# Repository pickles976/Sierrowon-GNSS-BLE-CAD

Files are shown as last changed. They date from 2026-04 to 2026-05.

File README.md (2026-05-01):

# README

## BOM

RS232 converter 
https://www.digikey.com/en/products/detail/texas-instruments/TRSF3232EIPWR/1909461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

ESP32-S3-Mini
https://www.digikey.com/en/products/detail/espressif-systems/ESP32-S3-MINI-1-N4R2/22597234
https://learn.adafruit.com/assets/110822

Power Supply
https://www.digikey.com/en/products/detail/recom-power/RPX-4-0-R/14312389

TODO: which pins from the GPS module do what?

## 12-Pin Connector Pin Assignment

| Header Pin | Signal | Module Pin | GPIO | Notes |
| --- |---|---|---|---|
| 01 | GND | — | — | Power rail |
| 02 | GND | — | — | Power rail |
| 03 | CS | 34 | IO38 | SPI — cleanest GPIO in range |
| 04 | IO_4 | 38 | IO42 | JTAG-capable, free as GPIO |
| 05 | MISO | 33 | IO37 | SPI — native FSPIQ |
| 06 | IO_3 | 37 | IO41 | JTAG-capable, free as GPIO |
| 07 | MOSI | 31 | IO35 | SPI — native FSPID |
| 08 | IO_2 | 36 | IO40 | JTAG-capable, free as GPIO |
| 09 | SCK | 32 | IO36 | SPI — native FSPICLK |
| 10 | IO_1 | 35 | IO39 | JTAG-capable, free as GPIO |
| 11 | 12V (GNSS Vin) | — | — | Power rail |
| 12 | 3.3V | — | — | Power rail |

> **Note:** Avoid using module pin 26 (IO26) as GPIO — on the N4R2, IO26 is internally tied to PSRAM in QIO mode and will cause corruption if driven externally. Avoid pins 39–40 (GPIO43/44, UART0 TX/RX) and pin 41 (IO45, VDD_SPI strapping pin). Pins 31–33 (IO35–IO37) have eFuse-determined defaults but are free in QIO flash mode. Pins 35–38 (IO39–IO42) are JTAG by default but freely reassignable; USB-JTAG still works regardless.

+12V trace is 2A, needs to be 1.5mm

Cheers
https://documentation.espressif.com/esp32-s3_datasheet_en.pdf#cd-pins-peri-assignment Page 27
https://documentation.espressif.com/esp32-s3-mini-1_mini-1u_datasheet_en.pdf Page 20

Output from GPS module: 9-36V (nominally 12V)
Output from Buck Converter: 3.3V

### Things to Study:
- schematic blocks
- pcb manufacturing
- set up redmine for documentation

```
for all resistors and capacitors you can use 0603 or 0805, diodes can be SMA, LEDs can also be 0603 or 0805, and kicad should have some footprints for some common pushbutton switches.

For the 52uF it would have to be 1206 most likely.. instead of putting +V_OUT its better just to put the actual voltage, like the +3V3 symbol, and then you dont need the power flags as well (unless you want to pass ERC everywhere)
usually you determine footprints for resistors and capacitors based on what is generally available on digi-key and mouser, but mostly they should all be 0603 and 0805
you can also just place a couple 22uF in parallel to get the 52uF since thats a more common size and we can reduce the BOM. Each additional part equates to an additional feeder on a pick and place and costs more to setup
the ESP should have a 22uF near the VIN pin, and you can use that some one 3x on the output of the buck converter

Ok I dont have a lot of time to go through this in detail, but some things I noticed in layout

Try to create more space between the USB-C connector and the ESP's antenna, preferrably swaping places with the USB-C and the 12 pin
Remove the little sliver of ground pour above the antenna, I would just move the ESP32 up more to eliminate that and get it right on the edge of the board.
I would add a lot of stitching vias around the GND pins of the ESP32 to connect the two ground pours on top and bottom.

I personally would recommend a 4-layer stackup so we can have a dedicated 3.3V ground pour and increase overall board capacitance, the ESP's wifi TX events can cause a good inrush current and from an EMI perspective we are creating a large current loops with 3.3V routed the way it is

```

### Workflow Stuff

The DXF files are generated from the full .step file of the BLE adapter. Then we import the outer ring and screw holes as the edge cuts of the board. A DXF containing all lines in the sketch is imported to the "user drawings" layer so we can see where our via holes need to go for the pins.

Layers
1. GND
2. GND
3. +3V3
4. GND

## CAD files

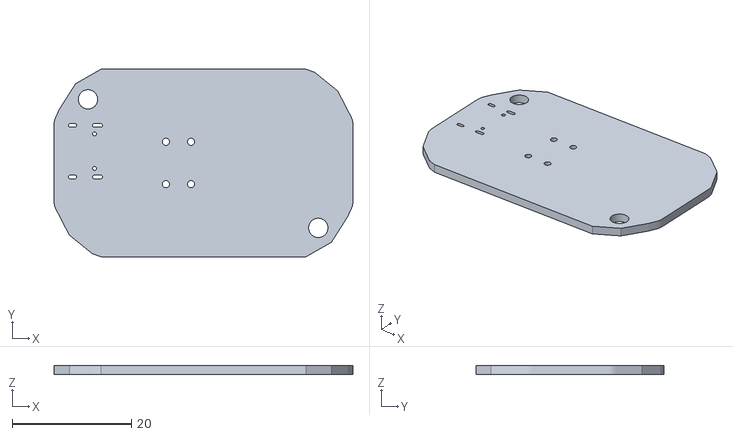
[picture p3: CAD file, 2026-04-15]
BLE-Module/.stl
50.0 x 31.4 x 1.51

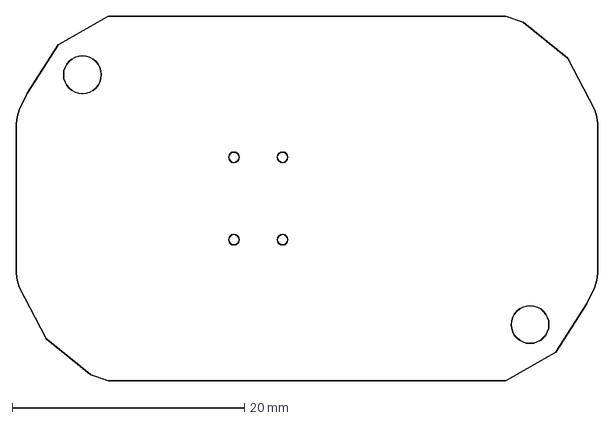
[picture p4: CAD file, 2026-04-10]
Reference/PCB for BLE interface.dxf
50.0 x 31.4 mm

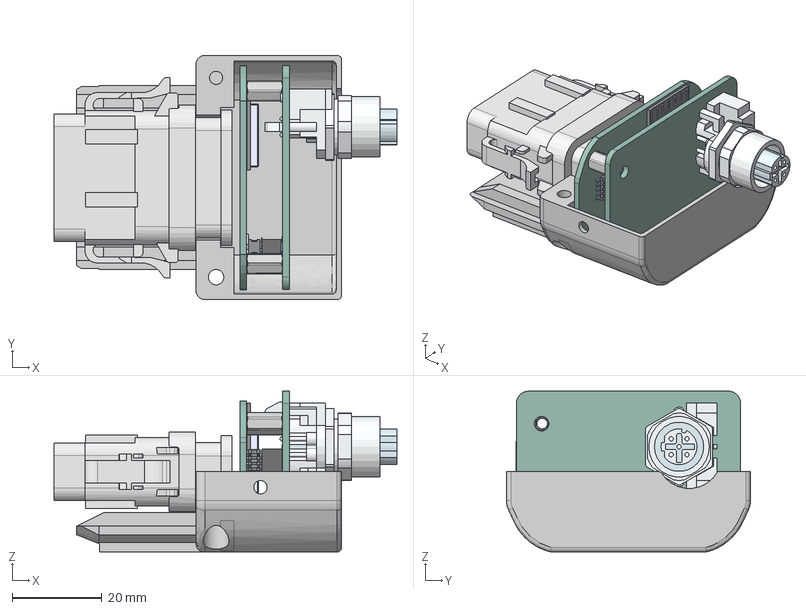
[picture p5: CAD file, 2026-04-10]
Reference/BLE V4 - Proto.step
76.5 x 54.5 x 35.9 mm
ESP32-S3-MINI-1-N4R2
ATM06-12SA-SR1GYPART1
ATM06-12SA-SR1GYSR
enclosure
PCB1
PCB2
FLE-105-01-DV_socket
C-96-01-05-DV
K-DOT-0.1675-0.281-0.005_polyamide_pick
FTSH-105-01-L-DV
94868A164_Female Threaded Hex Standoff x 2

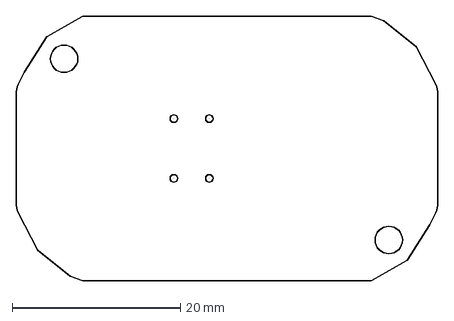
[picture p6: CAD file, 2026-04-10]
Reference/BOARD_TRACE.dxf
50.0 x 31.4 mm

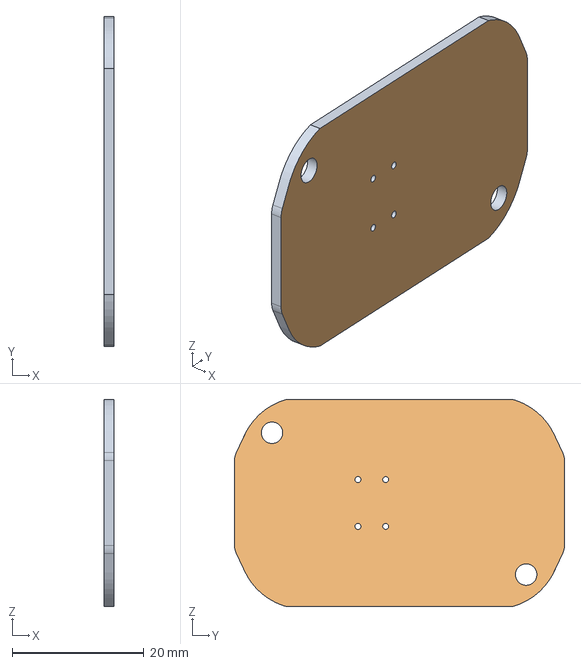
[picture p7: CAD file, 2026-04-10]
Reference/board_layout.FCStd
1.50 x 50.0 x 31.4 mm
PCB1
Binder

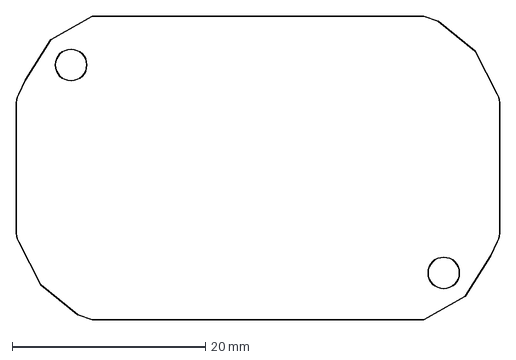
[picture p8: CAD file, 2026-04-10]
Reference/BOARD_OUTLINE.dxf
50.0 x 31.4 mm

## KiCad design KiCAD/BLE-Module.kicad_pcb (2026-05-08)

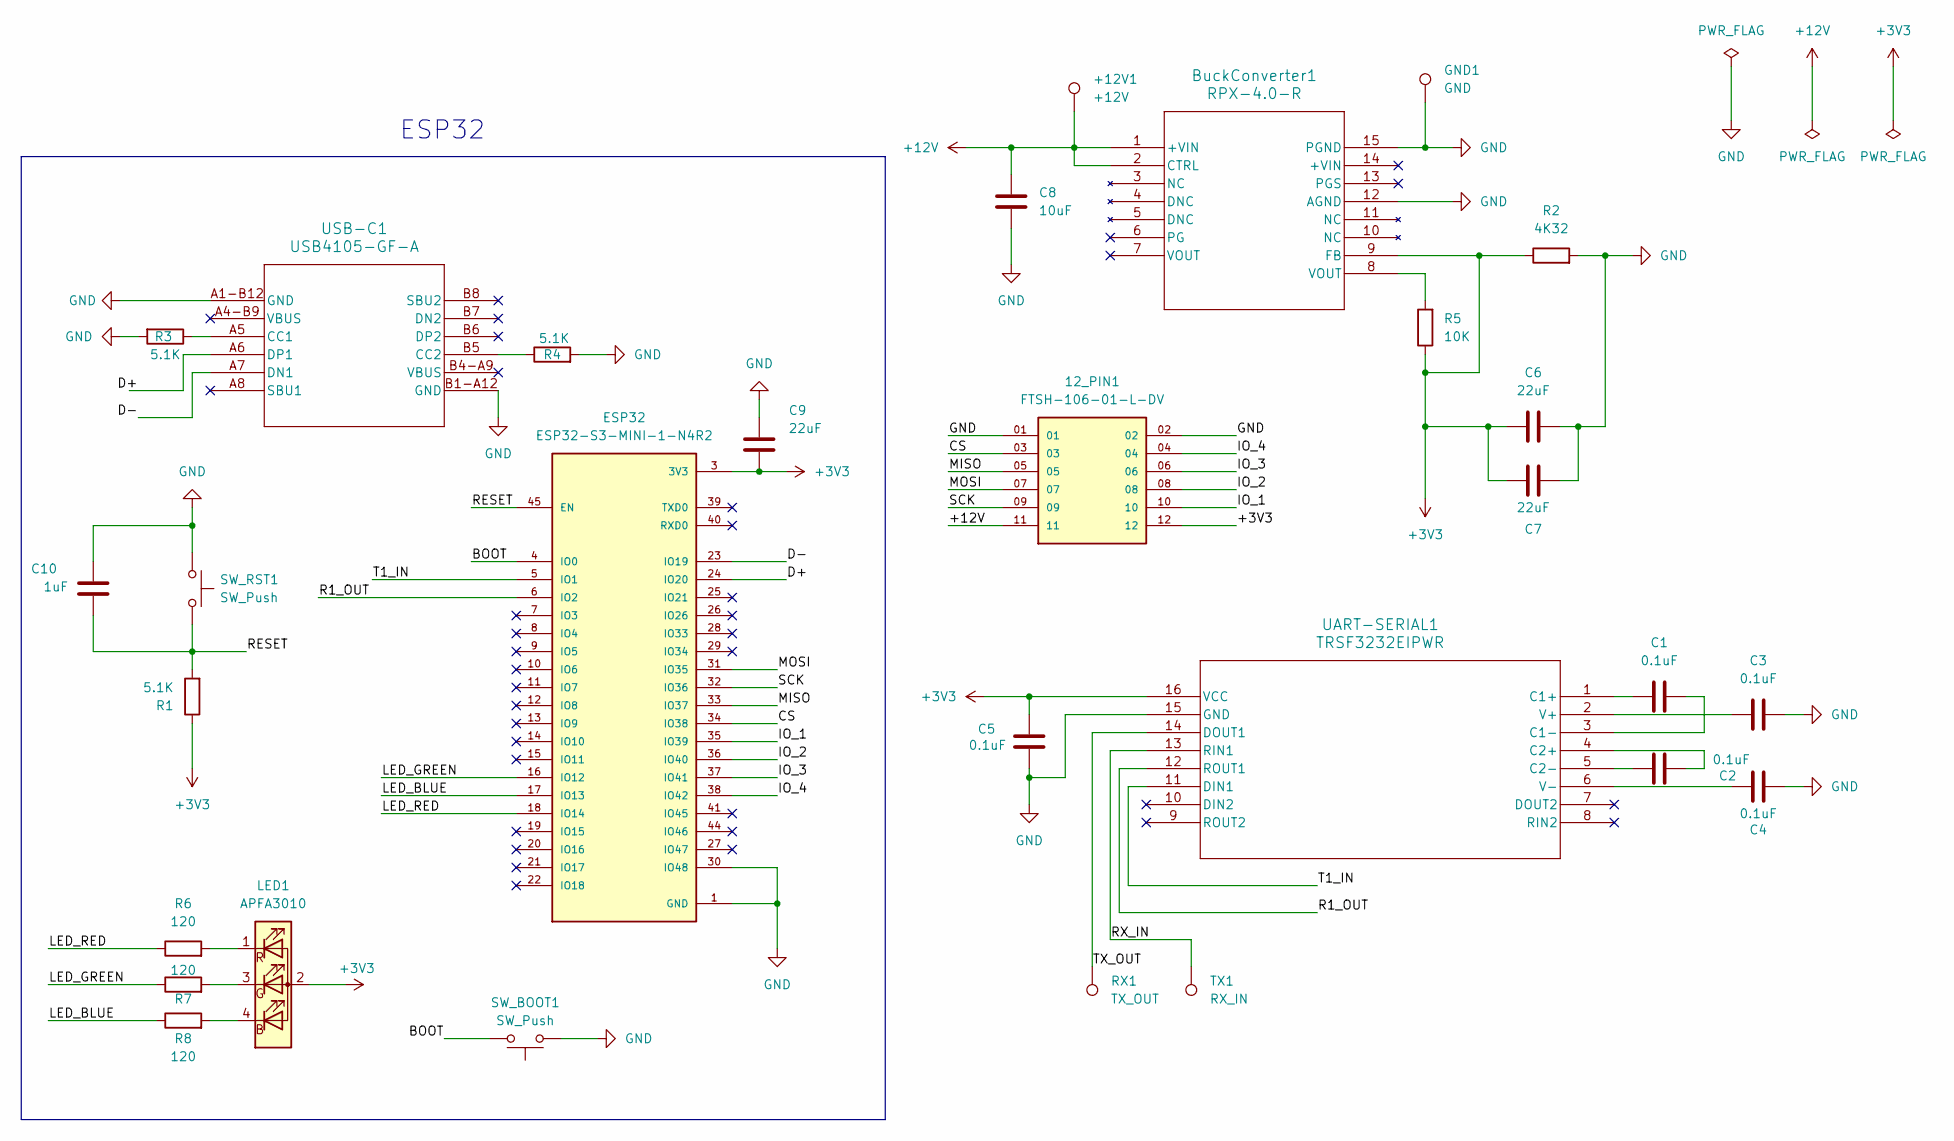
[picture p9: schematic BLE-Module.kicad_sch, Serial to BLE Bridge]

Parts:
12_PIN1: FTSH-106-01-L-DV; SAMTEC_FTSH-106-01-L-DV; PARTREV R
+12V1: +12V; TestPoint_THTPad_2.5x2.5mm_Drill1.2mm
BuckConverter1: RPX-4.0-R; RPX-4.0
C1, C2, C3, C4, C5: 0.1uF; C_0603_1608Metric
C6, C7, C9: 22uF; C_1206_3216Metric
C8: 10uF; C_1210_3225Metric
C10: 1uF; C_0603_1608Metric
ESP32: ESP32-S3-MINI-1-N4R2; XCVR_ESP32-S3-MINI-1-N4R2; PARTREV v0.6; DigiKey_Part_Number 1965-ESP32-S3-MINI-1-N4R2CT-ND
GND1: GND; TestPoint_THTPad_2.5x2.5mm_Drill1.2mm
LED1: APFA3010; LED_Kingbright_APFA3010_3x1.5mm_Horizontal
R1, R3, R4: 5.1K; R_0603_1608Metric
R2: 4K32; R_0603_1608Metric
R5: 10K; R_0603_1608Metric
R6, R7, R8: 120; R_0603_1608Metric
RX1: TX_OUT; TestPoint_THTPad_2.5x2.5mm_Drill1.2mm
SW_BOOT1: SW_Push; PTS526_08_CNK
SW_RST1: SW_Push; PTS526_08_CNK
TX1: RX_IN; TestPoint_THTPad_2.5x2.5mm_Drill1.2mm
UART-SERIAL1: TRSF3232EIPWR; PW16
USB-C1: USB4105-GF-A; USB4105_GCT

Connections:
+3V3: 12_PIN1.12, BuckConverter1.9 (FB), C5.1, C6.1, C7.1, C9.2, ESP32.3 (3V3), LED1.2 (A), R1.1, R2.1, R5.1, UART-SERIAL1.16 (VCC); also elsewhere on the board
+12V: 12_PIN1.11, +12V1.1 (1_1), BuckConverter1.1 (+VIN), BuckConverter1.2 (CTRL), C8.1; also elsewhere on the board
/BOOT: ESP32.4 (IO0), SW_BOOT1.2
/CS: 12_PIN1.03, ESP32.34 (IO38)
/D+: ESP32.24 (IO20), USB-C1.A6 (DP1)
/D-: ESP32.23 (IO19), USB-C1.A7 (DN1)
/IO_1: 12_PIN1.10, ESP32.35 (IO39)
/IO_2: 12_PIN1.08, ESP32.36 (IO40)
/IO_3: 12_PIN1.06, ESP32.37 (IO41)
/IO_4: 12_PIN1.04, ESP32.38 (IO42)
/LED_BLUE: ESP32.17 (IO13), R8.1
/LED_GREEN: ESP32.16 (IO12), R7.1
/LED_RED: ESP32.18 (IO14), R6.1
/MISO: 12_PIN1.05, ESP32.33 (IO37)
/MOSI: 12_PIN1.07, ESP32.31 (IO35)
/R1_OUT: ESP32.6 (IO2), UART-SERIAL1.12 (ROUT1)
/RESET: C10.1, ESP32.45 (EN), R1.2, SW_RST1.2
/RX_IN: TX1.1 (1_1), UART-SERIAL1.13 (RIN1)
/SCK: 12_PIN1.09, ESP32.32 (IO36)
/T1_IN: ESP32.5 (IO1), UART-SERIAL1.11 (DIN1)
/TX_OUT: RX1.1 (1_1), UART-SERIAL1.14 (DOUT1)
GND: 12_PIN1.01, 12_PIN1.02, BuckConverter1.12 (AGND), BuckConverter1.15 (PGND), C3.2, C4.2, C5.2, C6.2, C7.2, C8.2, C9.1, C10.2, ESP32.1 (GND), ESP32.2 (GND), ESP32.30 (IO48), ESP32.42 (GND), ESP32.43 (GND), ESP32.46 (GND), ESP32.47 (GND), ESP32.48 (GND), ESP32.49 (GND), ESP32.50 (GND), ESP32.51 (GND), ESP32.52 (GND), ESP32.53 (GND), ESP32.54 (GND), ESP32.55 (GND), ESP32.56 (GND), ESP32.57 (GND), ESP32.58 (GND), ESP32.59 (GND), ESP32.60 (GND), ESP32.61 (GND), ESP32.61_1 (GND), ESP32.61_2 (GND), ESP32.61_3 (GND), ESP32.61_4 (GND), ESP32.61_5 (GND), ESP32.61_6 (GND), ESP32.61_7 (GND), ESP32.61_8 (GND), ESP32.62 (GND), ESP32.63 (GND), ESP32.64 (GND), ESP32.65 (GND), GND1.1 (1_1), R2.2, R3.2, R4.2, SW_BOOT1.1, SW_RST1.1, UART-SERIAL1.15 (GND), USB-C1.A1-B12 (GND), USB-C1.B1-A12 (GND); also elsewhere on the board
unnamed 23: BuckConverter1.8 (VOUT), R5.2; also elsewhere on the board
unnamed: LED1.4 (B), R8.2
unnamed: LED1.3 (G), R7.2
unnamed: LED1.1 (R), R6.2
unnamed: C1.1, UART-SERIAL1.1 (C1+)
unnamed: C1.2, UART-SERIAL1.3 (C1-)
unnamed: C2.2, UART-SERIAL1.4 (C2+)
unnamed: C2.1, UART-SERIAL1.5 (C2-)
unnamed: C3.1, UART-SERIAL1.2 (V+)
unnamed: C4.1, UART-SERIAL1.6 (V-)
unnamed: R3.1, USB-C1.A5 (CC1)
unnamed: R4.1, USB-C1.B5 (CC2)

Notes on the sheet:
ESP32

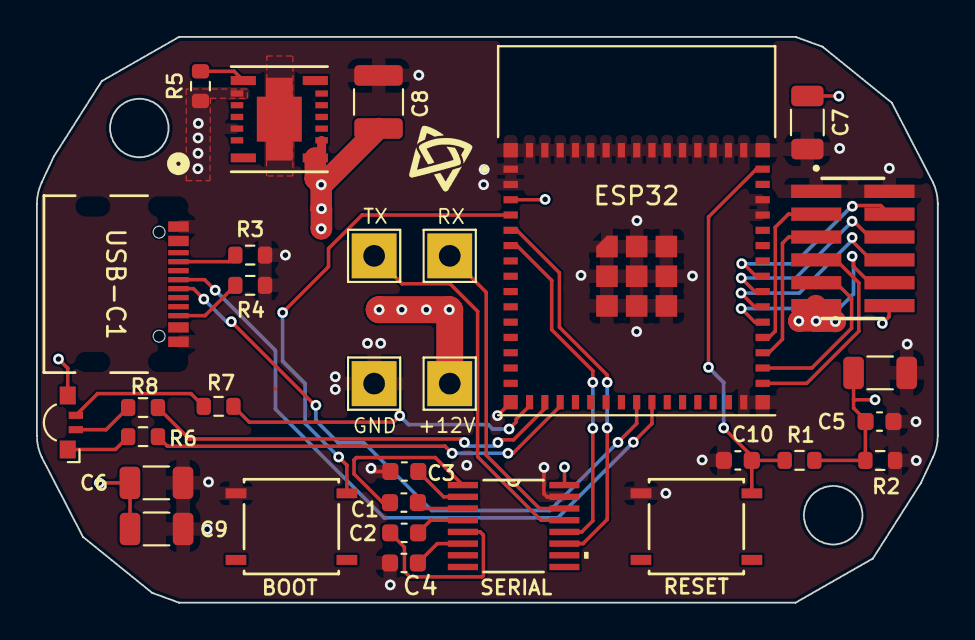
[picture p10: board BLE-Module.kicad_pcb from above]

Board: 4 copper layers, 50.0 x 31.4 mm, 31 parts (0 on the bottom side), 34 nets.

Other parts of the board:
BuckConverter: RPX-4.0-R; RPX-4.0
C_OUT2: 22uF; C_1206_3216Metric

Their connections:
+3V3: BuckConverter.9 (FB), C_OUT2.1; also elsewhere on the board
+12V: BuckConverter.1 (+VIN), BuckConverter.2 (CTRL); also elsewhere on the board
GND: BuckConverter.12 (AGND), BuckConverter.15 (PGND), C_OUT2.2; also elsewhere on the board
unnamed 23: BuckConverter.8 (VOUT); also elsewhere on the board

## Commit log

2026-04-10 init commit
    [10164359-00011LF.STEP, BLE V4 - Proto.step, BLE-Module.kicad_pcb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]
2026-04-15 Redesigned board
    [BLE-Module.kicad_pcb, BLE-Module.kicad_sch]
2026-04-15 Picked USB-C receptacle
    [BLE-Module.kicad_pcb, BLE-Module.kicad_sch, USB4105-GF-A.STEP]
2026-04-15 Added text and graphics
    [BLE-Module.kicad_pcb, BLE-Module.kicad_sch]
2026-04-15 Added common-anode LED
    [10164359-00011LF.STEP, APFA3010LSEEZGKQBKC.step, BLE-Module.kicad_pcb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]
2026-04-15 updated docs
    [.stl, BLE-Module.kicad_pcb, BLE-Module.kicad_sch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]
2026-04-17 Saving before I change the power plane
    [BLE-Module.kicad_pcb, BLE-Module.kicad_sch]
2026-04-17 Changed design to 4-layer
    [BLE-Module.kicad_pcb, BLE-Module.kicad_sch]
2026-04-29 Refactored stuff
    [.stl, BLE V4 - Proto.step, BLE-Module.kicad_pcb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]
2026-05-08 Fixed library paths
    [BLE-Module.kicad_pcb]
